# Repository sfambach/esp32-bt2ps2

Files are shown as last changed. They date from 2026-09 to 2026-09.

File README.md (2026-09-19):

1/9/24: Serial Mouse support is out for v0.7! Check notes on [release](https://github.com/Hamberthm/esp32-bt2ps2/releases)

24/8/24: Mouse and Multimedia Key support is out for v0.6! Check notes on release

Tested Bluetooth Keyboards and Mice (Please add your own!): [Excel spreadsheet](https://1drv.ms/x/c/496a36eb8f7bab52/EVKre4_rNmoggEllRQIAAAABdvU2lrtNIQN1tRJOs5V3sw?e=jx4JUH)

FreeRTOS ticking rate of 1000hz and other configs are critical. Be sure to use the default SDKconfig.defaults file included!

# ESP32 Bluetooth/BLE to PS/2 keyboard/mouse adapter

## Hardware (this fork)

This fork adds **carrier boards** for the adapter in [`hardware/`](hardware/README.md): an SMD and a THT version,
each for a plugged-in *D1 mini ESP32* or a soldered-on *ESP32-WROOM-32E*, with level shifters and a 4-pin
connector for a PS/2 or AT keyboard cable. KiCad 10 files, Gerbers for JLCPCB and schematics are included;
downloads are on the [release v0.1](https://github.com/sfambach/esp32-bt2ps2/releases/tag/v0.1).

> ⚠️ **The boards are not tested yet** — designed and DRC-checked, but not manufactured. Details and open points in
> [`hardware/README.md`](hardware/README.md).

| SMD | THT |
|---|---|
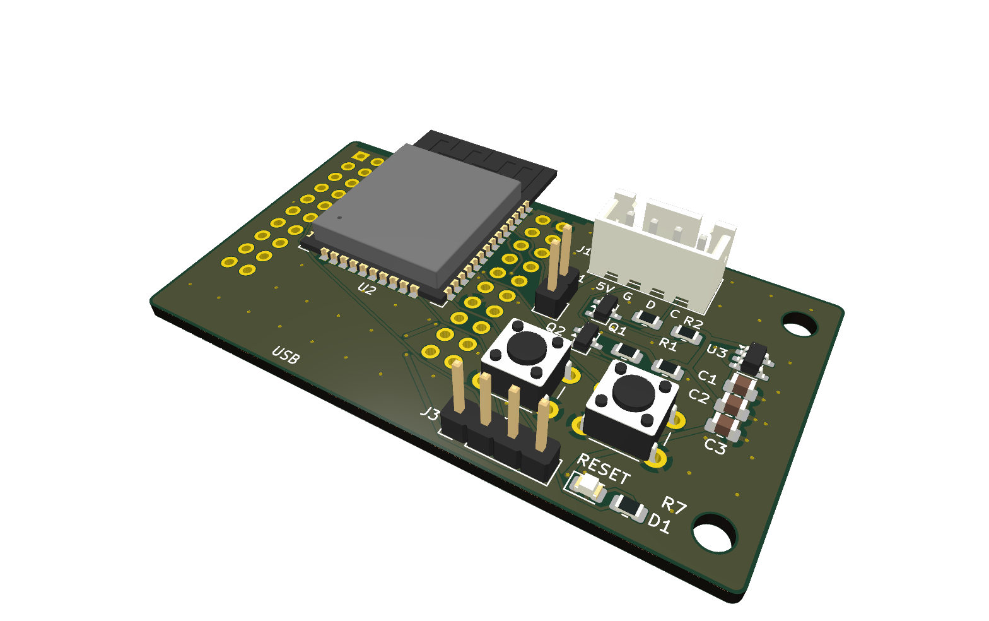
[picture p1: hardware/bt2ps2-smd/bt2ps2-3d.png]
SMD board
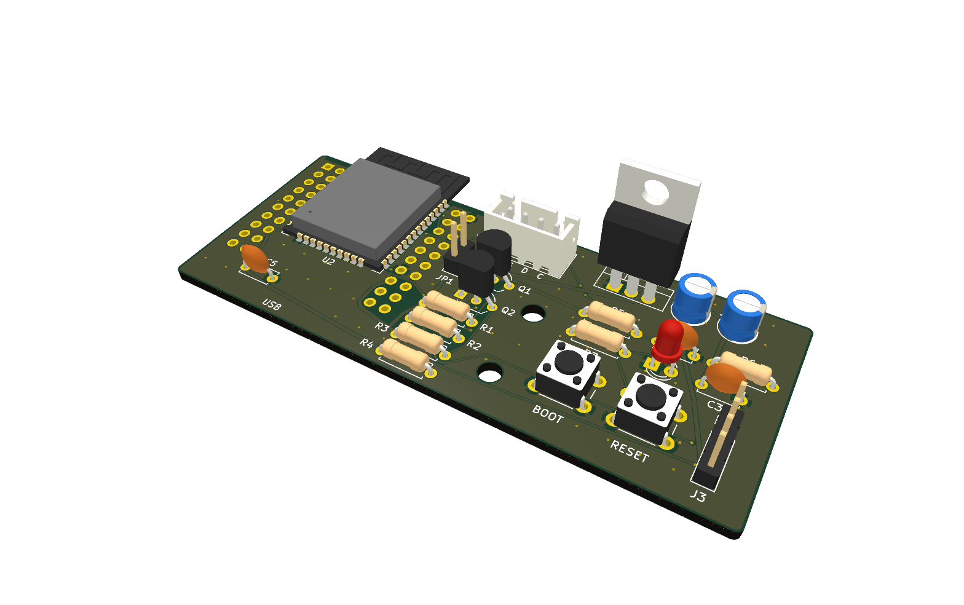
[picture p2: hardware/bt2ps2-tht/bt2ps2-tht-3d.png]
THT board
|  |  |
| SMD schematic | THT schematic |

Project to adapt a Bluetooth or BLE keyboard and/or mouse to use on a computer with compatible PS/2 keyboard/mouse connector/s, wirelessly.
Note that big DIN 5 pin connectors ("AT" keyboard) and Mini-DINs (the violet ones) are equally supported.

YouTube demo: https://youtu.be/2PVjWfAAJFE

<p align="center">
  Mini-DIN version
</p>

# Compatibility

Tested Bluetooth Keyboards and Mice (Please add your own!): https://1drv.ms/x/s!AlKre4_rNmpJiYpl1v4KcbK1Pm77zA?e=0I6QRB

Working under latest ESP-IDF v5.3.0 (not v5.3.3 or higher), compiled on Visual Studio Code. Multi-device support may not work on lower versions of the SDK.

**Developed and tested on the ESP32 DevKit rev 1 board, other variants may not work!**

WARNING: This project is for use in a plain ESP-32 module with BLE and BT Classic support and dual core processor. If you have another variant like C3, you'll have to adapt the code.

* ESP32 S3/C3 (BLE only boards): Check https://github.com/Hamberthm/esp32-bt2ps2/issues/3
* USB-HID instead of PS/2: Check https://github.com/Hamberthm/esp32-bt2ps2/issues/4

# Electrical connections

DIN and Mini-DIN connectors have similar pinout but in different arrangements.

Please use a multimeter and online info to make your cable. Beware of voltage present on the port, you can short and fry things!

Connections:

| ESP32 pin | PS/2 pin | example color | Notes |
| --- | --- | --- |  --- |
| 23 or any | DATA | orange | Repeat on other pin for mouse bus  |
| 22 or any | CLK | white | Repeat on other pin for mouse bus  |
| GND | GND | black | Always connect! |
| Vin | +5v | red | Disconnect if using USB power! |

You can change the DATA and CLK pins to whatever suits your fancy using these lines in the main.cpp file:

```cpp
const int KB_CLK_PIN = 22;
const int KB_DATA_PIN = 23;

const int MOUSE_CLK_PIN = 26;
const int MOUSE_DATA_PIN = 25;
```
Note: Pin 12 & 13 are ideal to solder a connector so you can use Vin, GND, 13 and 12 all in a row (ESP32 DevKit rev 1 boards). BEWARE that pin 12 is a strapping pin on the ESP32 and the module will FAIL to boot due to high signals from the PS/2 port. You can remove the strapping function of pin 12 by blowing an [eFuse](https://docs.espressif.com/projects/esptool/en/latest/esp32s2/espefuse/index.html) on your board. Use the following command:

```
python espefuse.py --port COM4 set_flash_voltage 3.3V
```

Also, applying voltage to pins 1 & 3 (U0 TXD and RXD) could cause the serial communication not to work, thus making serial console output impossible. Be careful on the ones you choose!

There is no need to connect the 5 volts from the port if you wish to power the board over USB. For debugging I recommend you leave it disconnected, as you can end up back-feeding 5 volts back to the PS/2 port, bad things can happen. Once all is working and you don't want to debug anymore, the 5 volts from the port are enough to power the board over the Vin (regulated) pin, making this a pretty neat standalone device!

NOTE: Don't leave the GND cable from the PS2 port floating, otherwise communication won't work! Always connect GND cable to the board even if you're using external power.

Note: ESP32 is **unofficially** 5V tolerant, so you can directly connect PS/2 pins to the board, that's my setup on my rev v1 board and I had no problems. However, you may use a logic level converter.

# Building and flashing

*Note there's a binary release available!

Project works as-is under Visual Studio Code (2024). You need to have the Espressif IDF extension installed and the v5.3.0 of the ESP-IDF SDK. Workflow is as follows:

1- Install Visual Studio Code

2- On the left, open the extensions panel

3- Search and install the Espressif IDF extension

4- Open the command prompt pressing Ctrl+Shift+P

5- Execute command "ESP-IDF: Configure ESP-IDF extension"

6- Select Express, and under "Select ESP-IDF version" choose v5.3.0 (As of 19/6/25 v5.3.3 or higher are NOT working!)

7- After installation, select File > Open Folder and open the ESP32-BT2PS2 project folder

8- Start building by pressing Ctrl+E and then B, or using the Build button in the bottom bar

9- If succesfully built, connect and flash your ESP32 board (Ctrl+E then F, or the flash button)

Refer to the following link for more instructions:

* https://github.com/espressif/vscode-esp-idf-extension/blob/master/docs/tutorial/install.md

Once succesfully built and flashed, you're ready to rock! (your BLE keyboard on an ancient computer, that is).

# Usage and debugging

Once powered up and first of all, the code will create and init an `esp32_ps2dev::PS2Keyboard` object, so it can start to talk to the computer as soon as possible. This is critical because during boot the BIOS can send different commands to the module to test the presence of the keyboard.

After PS/2 init, the module scans for nearby Bluetooth and BLE devices. If the last bonded keyboard is in range, it will try to connect to it using the keys stored on the NVS flash, so no pairing is needed for every connection. If it doesn't detect a previously bonded device, it will try to connect to the nearest keyboard in pairing mode. If both processes fail, it will wait one second and scan again until it finds anything.

IMPORTANT: Is recommended to do the pairing to the keyboard BEFORE connecing the board to a PS/2 port. For this, connect a charger or power bank to the ESP's USB port and pair your device more comfortably.

For v0.6, you can invoke pairing during execution (blue LED on) at any time. Press the "BOOT" button on the rev v1 board, essentially shorting GPIO_0 to ground. LED will go off and enter pairing mode. To cancel pairing, press and hold for 3 seconds (pairing aborting does not work on startup pairing).

**LED off: Pairing mode activated. LED on: normal execution, only previously paired devices can connect at any time.**

### >> BLE KEYBOARD OR MOUSE PAIRING: 
Set keyboard or mouse in pairing mode and power on the board. No code entry required.

### >> BLUETOOTH CLASSIC KEYBOARD PAIRING (code pairing):

1- Set keyboard in pairing mode and power on the board.

2- Wait until you see a short blast of quick flashes, then pay attention:

3- For each code digit, the board will flash the LED the number of times equal to the digit.

4- Press each digit on the keyboard as you read them (do not wait until it finishes! Some keyboards have a timeout).

5- If the digit is 0, a steady light will show for 1.5 seconds instead of the digit.

6- When you see the blast of quick flashes again, press ENTER.

OR you can always look at the code using the Serial monitor console, whatever you find easier, you fancy boy.

### >> BLUETOOTH CLASSIC KEYBOARD PAIRING, LEGACY PROCEDURE (legacy code pairing):

In older keyboards, the user must enter a custom code on the host device and then on the keyboard. Since we can't input it easily on the ESP32, the code is fixed to 1234.

1- Set keyboard in pairing mode and power on the board

2- Watch the Serial Ouput Console. Wait for the board finishing the scan and for the message "Waiting pairing code entry..."

3- Type 1234 on the keyboard then press ENTER.

Note: For Legacy Mode, no LED output is possible at the moment, so we need to check the serial console for the right time to enter the code. 

---

- If paired and working correctly, the board should blink the LED with each key press on the keyboard, or with each click on the mouse

Once connected you can start using your keyboard and mouse, blue LED should be on. Remove any USB power source and connect the board to the PS/2 compatible system and enjoy. Remember PS/2 is NOT a HOT-SWAP protocol, please only connect the board with the system totally OFF.

You can hot-disconnect the keyboard and mouse for models that support multiple devices hopping. The module will detect the disconnection and repeatedly try to reconnect while you're using other systems, so it will be back online as soon as the keyboard gets up to the ESP32 again. This is critical for keyboards/mouses that go to sleep and disconnect, or if you swap between computers using a multi-connection keyboard. 

Please note that pairing is only done after power up. If you wish to pair a new device, please reset the module with the reset button or power off and on the computer (not just reset it, because we need a power cycle). Note that if a previously paired device is on and in range, it will always connect to it first. Also invoke pairing after power on (LED on) by using the BOOT button or shorting GPIO_0 to ground.

In case something doesn't work, you'll need to debug. 

If the blue light on the module lights up and your keyboard connects, but it doesn't work, first of all reset your system. If it still doesn't work, then you'll need to enable debugging in the `esp32-ps2dev.cpp` file using `#DEFINE _ESP32_PS2DEV_DEBUG_`. Check for "PS/2 command received" messages and see where it hangs, or what the BIOS doesn't like. This is advanced so if you need help, make a new issue.

# TODO
 * Test on many keyboards and mouses.
 * Improve stability.
 * Clean up the code.
 * Test against various hosts.

# Reference
- http://www-ug.eecg.toronto.edu/msl/nios_devices/datasheets/PS2%20Protocol.htm
- http://www-ug.eecg.toronto.edu/msl/nios_devices/datasheets/PS2%20Mouse%20Protocol.htm
- http://www-ug.eecg.toronto.edu/msl/nios_devices/datasheets/PS2%20Keyboard%20Protocol.htm

# History
Using code and hard work from these folks:
 
 * https://playground.arduino.cc/ComponentLib/Ps2mouse/
 * https://github.com/grappendorf/arduino-framework/tree/master/ps2dev
 * https://github.com/dpavlin/Arduino-projects/tree/master/libraries/ps2dev
 * ps2 library Written by Chris J. Kiick, January 2008. https://github.com/ckiick
 * modified by Gene E. Scogin, August 2008.
 * modified by Tomas 'Harvie' Mudrunka 2019. https://github.com/harvie/ps2dev
 * modified for ESP32 by hrko 2022. https://github.com/hrko/esp32-ps2dev
 * fixed for PC compatibility and stability by Hambert, 2023. https://github.com/Hamberthm/esp32-ps2dev
 * bt-keyboard library by Guy Turcotte, 2022. https://github.com/turgu1/bt-keyboard
 * adapted to Arduino IDE and added improvements by Hambert, 2023. https://github.com/Hamberthm/bt-keyboard

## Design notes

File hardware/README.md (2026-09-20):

# Hardware: carrier boards for esp32-bt2ps2

> ⚠️ **Untested.** These boards have been designed and checked (KiCad ERC/DRC clean), but **no board has been
> manufactured or tested yet**. Use at your own risk and check everything with a multimeter before connecting
> it to a computer. Feedback welcome.
>
> ⚠️ **Noch nicht getestet.** Die Platinen sind entworfen und geprüft (ERC/DRC ohne Befund), aber **noch nicht
> gefertigt und nicht erprobt.**

Two boards for the firmware in this repository — **keyboard only (version 1)**, same pins as the firmware
defaults (`KB_CLK_PIN = 22`, `KB_DATA_PIN = 23`), so the firmware runs unchanged.

| | [SMD](bt2ps2-smd) | [THT](bt2ps2-tht) |
|---|---|---|
| ESP32 | **A:** D1 mini ESP32 plugged in, **or B:** ESP32-WROOM-32E soldered on | same |
| Level shifter 5 V ↔ 3.3 V | 2 × BSS138 (SOT-23) + 10 kΩ | 2 × 2N7000 (TO-92) + 10 kΩ |
| 3.3 V regulator (variant B only) | AP2112K-3.3 | LD1117V33 (TO-220) |
| Passives | 0805 | through-hole (the WROOM is the only SMD part) |
| Size | 61.0 × 34.1 mm | 83.0 × 34.1 mm |

Both are 2-layer boards made for JLCPCB's standard process (1.6 mm, 1 oz, HASL). Designed with **KiCad 10**.

**Downloads:** Gerber ZIPs, KiCad projects and schematics are attached to the
[release v0.1](https://github.com/sfambach/esp32-bt2ps2/releases/tag/v0.1).

## SMD board

SMD board, 3D view

SMD schematic

## THT board

THT board, 3D view

THT schematic

## Enclosures

3D-printable cases for both boards (shell + lid, OpenSCAD source and STLs) are in [`case/`](case/README.md).

## What is on the board

- **J1 – keyboard connector to the PC** (JST-XH, 4 pins): `1 = +5V`, `2 = GND`, `3 = DATA`, `4 = CLK` (printed as
  `5V G D C`). Crimp a cable to a PS/2 (Mini-DIN-6) or AT (DIN-5) plug:

  | J1 | PS/2 Mini-DIN-6 pin | AT DIN-5 pin |
  |---|---|---|
  | 1 +5V | 4 | 5 |
  | 2 GND | 3 | 4 |
  | 3 DATA | 1 | 2 |
  | 4 CLK | 5 | 1 |

  Pinouts as commonly documented — **measure your plug before use.**
- **JP1 – 5 V from the PC.** Pull the jumper while the board is powered over USB (or J3), otherwise 5 V is fed back
  into the PC's keyboard port — the same warning as in the main README.
- **Variant A (default):** a *D1 mini ESP32* (MH-ET LIVE MiniKit / "D1 mini ESP32 ESP-WROOM-32", 4 rows of pins,
  39 × 32 mm) on female headers. Programming via its own USB port. Its USB end is flush with the board edge,
  its antenna overhangs the opposite edge.
- **Variant B:** an ESP32-WROOM-32E soldered between the inner header rows, antenna over the board edge. Adds the
  3.3 V regulator, EN/BOOT circuitry, **BOOT** and **RESET** buttons, a status LED on IO2 and **J3** for a
  USB-serial adapter: `1 GND`, `2 ESP TXD → adapter RX`, `3 ESP RXD → adapter TX`, `4 +5V`.
  Populate **either A or B**, never both.
- IO25/IO26 are kept free for the mouse port (planned for version 2).

## Files per board

| File | |
|---|---|
| `*.kicad_pro`, `*.kicad_sch`, `*.kicad_pcb` | KiCad 10 project |
| `*.kicad_dru` | design rules for JLCPCB |
| `*.kicad_sym`, `*.pretty/` | symbol and footprint of the D1 mini ESP32 socket |
| `*-schaltplan.pdf` / `.svg` | schematic |
| `fertigung/*-jlcpcb-gerber.zip` | Gerber + drill files, ready to upload to JLCPCB |
| `fertigung/bestueckung-*.pdf` | assembly drawings |
| `fertigung/*-ibom.html` | interactive BOM (open in a browser) |
| `fertigung/stueckliste.csv` | bill of materials |
| `fertigung/*-jlcpcb-positionen.csv` | pick-and-place data, origin at the lower left corner of the board |

## Notes and open points

- **2N7000 at 3.3 V gate (THT board):** Vgs(th) is typically 2.1 V but may be up to 3 V. It should work for the
  low PS/2 currents — try it on a breadboard first. A BS170 is *not* a drop-in replacement (different pinout).
- The D1 mini footprint is based on [r0oland/ESP32_mini_KiCad_Library](https://github.com/r0oland/ESP32_mini_KiCad_Library)
  and was checked against the pinout of an actual board; the outline and antenna position are estimated (±1 mm).
- The traces were laid out by a simple grid router and checked with KiCad's DRC — functional, not pretty.

Designed by Stefan Fambach — [fambach.net](https://www.fambach.net). The hardware in this folder is licensed under the
[MIT License](LICENSE), like the firmware.

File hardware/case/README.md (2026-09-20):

# 3D-printed enclosures

One OpenSCAD file, two enclosures (SMD and THT board). Each is **split horizontally at half height**: a bottom tray and a top frame with the cover plate.

| | SMD board | THT board |
|---|---|---|
| Assembled, outer | 72.3 × 49.8 × 24.6 mm | 94.3 × 49.8 × 24.6 mm |
| Bottom / top | 12.0 mm / 12.6 mm tall | same |
| STL | `bt2ps2-smd-unterteil.stl` (bottom), `bt2ps2-smd-oberteil.stl` (top) | `bt2ps2-tht-unterteil.stl`, `bt2ps2-tht-oberteil.stl` |

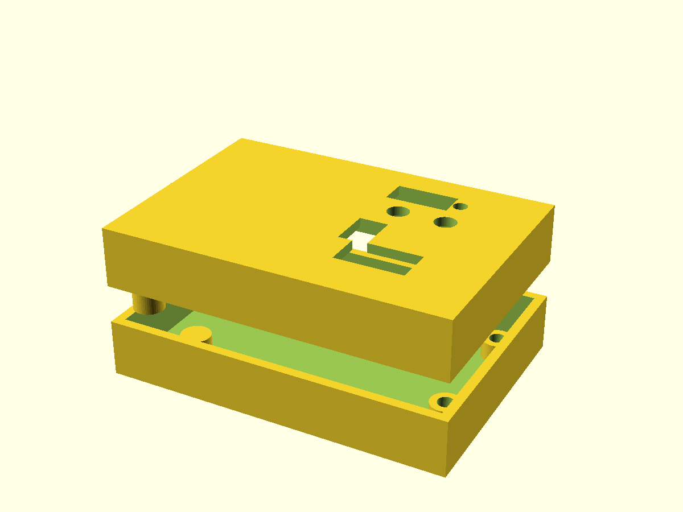
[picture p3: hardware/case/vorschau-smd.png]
SMD enclosure


The box is larger than the board because the ESP32 module sticks out at both ends: the antenna (7 mm of air, no
copper and no screw underneath) and the D1 mini's USB socket (4.6 mm).

**How it holds together:** four M3 screws, all from below. They pass through the bottom tray into columns that hang
down from the top cover. **Two of them go through the board's mounting holes** — the board sits on a 4 mm post of
the bottom part and the column of the top part presses on it, so board and case share the same screw. The other two
stand in the free strip left of the board. Screw heads sit in countersinks, so the case stands flat.

**Openings in the top part:** two buttons (⌀4.6 mm), LED (⌀3.0 mm SMD board, ⌀3.6 mm THT board), the JST connector J1 (the
cable leaves through it), the 5 V jumper JP1, and the programming header J3. **USB** is a cutout in the side wall
at socket height.

**You need:** tactile switches **6 × 6 mm with a long plunger, 17 mm overall** ("6x6x17") — then the plunger ends
flush with the cover; and four M3 × 16 self-tapping screws (2.5 mm pilot holes); M3 × 12 works too.

**Rebuild or modify** — wall thickness, inner height, clearances and every cutout are parameters at the top of
[`bt2ps2-gehaeuse.scad`](bt2ps2-gehaeuse.scad):

```bash
openscad -D 'variante="smd"' -D 'teil="unterteil"' -o bt2ps2-smd-unterteil.stl bt2ps2-gehaeuse.scad
```

`variante` is `smd` or `tht`, `teil` is `unterteil` (bottom), `oberteil` (top) or `beides` (both, for viewing only).
Print the top part upside down — the columns then point upwards and need no supports.

> ⚠️ **Untested like the boards:** dimensions are taken from the KiCad files, but nothing has been printed or
> fitted yet. Print a test corner with one screw post and one button hole first.

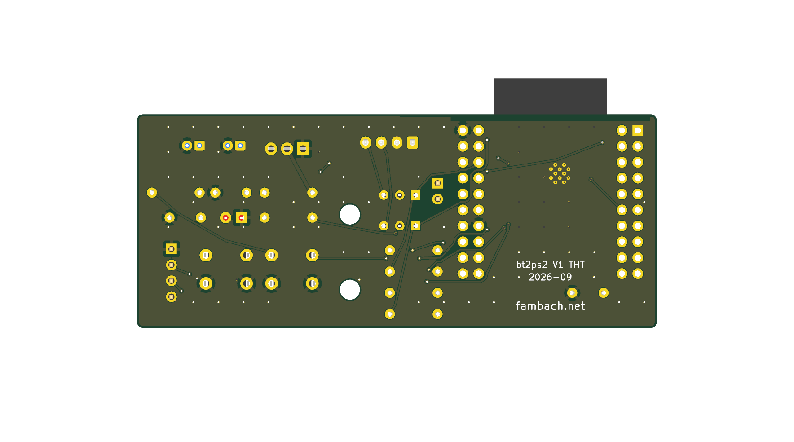
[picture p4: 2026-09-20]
hardware/bt2ps2-tht/bt2ps2-tht-unten.png

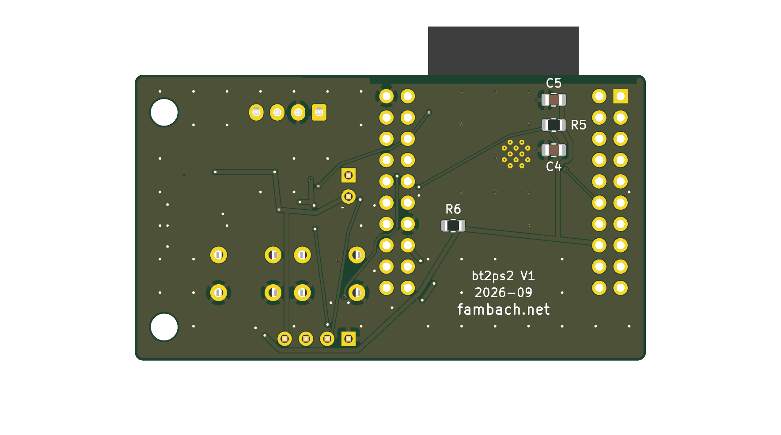
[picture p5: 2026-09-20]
hardware/bt2ps2-smd/bt2ps2-unten.png

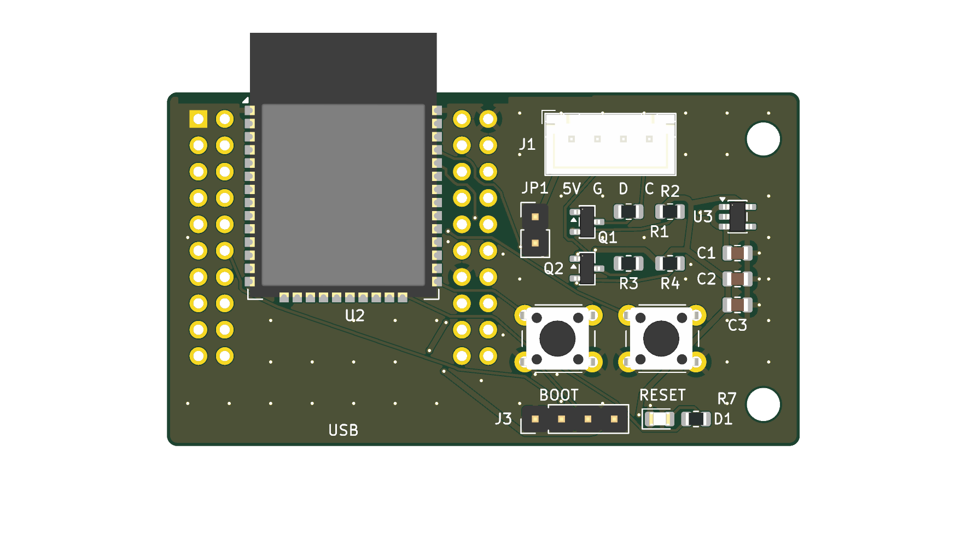
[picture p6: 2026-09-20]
hardware/bt2ps2-smd/bt2ps2-oben.png

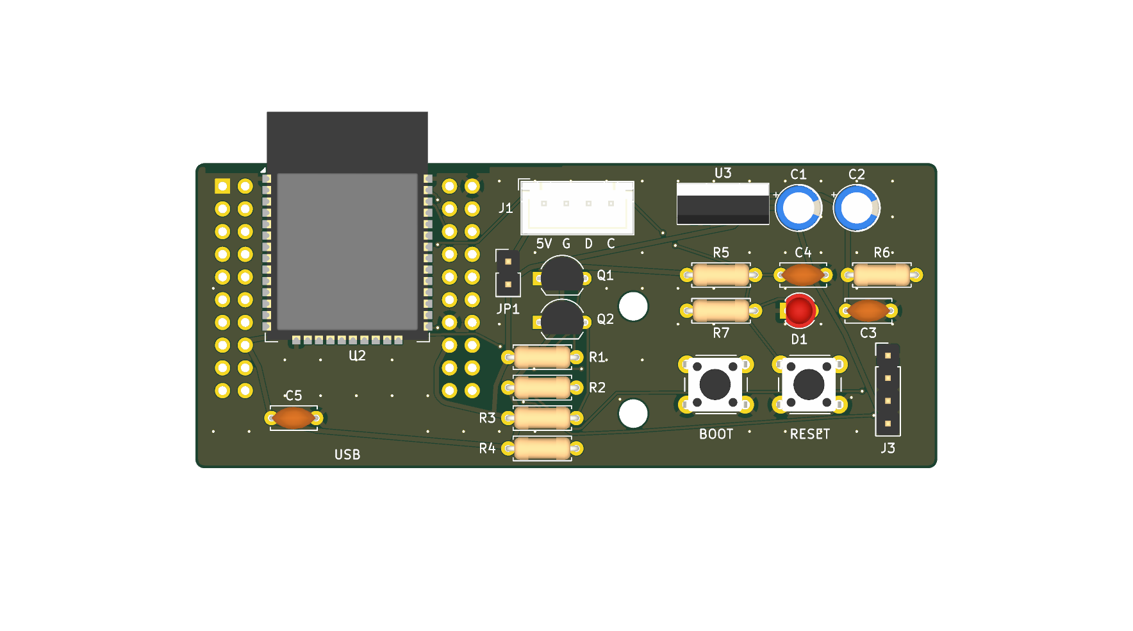
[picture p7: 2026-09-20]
hardware/bt2ps2-tht/bt2ps2-tht-oben.png

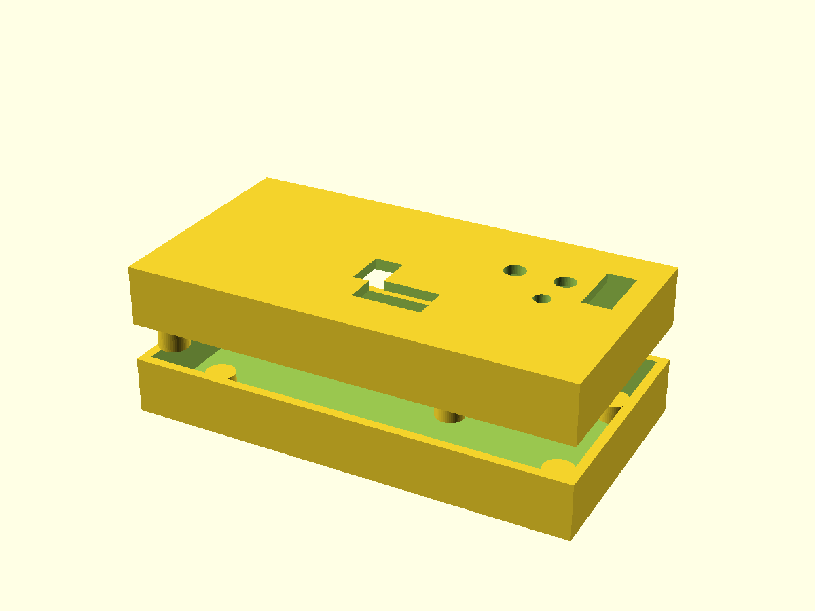
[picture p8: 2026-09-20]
hardware/case/vorschau-tht.png

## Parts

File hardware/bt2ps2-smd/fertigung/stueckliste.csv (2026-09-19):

Bauteile | Wert | Gehaeuse | Anzahl
C1,C2 | 10u | Capacitor_SMD:C_0805_2012Metric | 2
C3,C5 | 100n | Capacitor_SMD:C_0805_2012Metric | 2
C4 | 1u | Capacitor_SMD:C_0805_2012Metric | 1
D1 | blau | LED_SMD:LED_0805_2012Metric | 1
J1 | PS2_Tastatur | Connector_JST:JST_XH_B4B-XH-A_1x04_P2.50mm_Vertical | 1
J3 | Programmer | Connector_PinHeader_2.54mm:PinHeader_1x04_P2.54mm_Vertical | 1
JP1 | 5V_vom_PC | Connector_PinHeader_2.54mm:PinHeader_1x02_P2.54mm_Vertical | 1
Q1,Q2 | BSS138 | Package_TO_SOT_SMD:SOT-23 | 2
R1-R6 | 10k | Resistor_SMD:R_0805_2012Metric | 6
R7 | 1k | Resistor_SMD:R_0805_2012Metric | 1
SW1 | BOOT | Button_Switch_THT:SW_PUSH_6mm | 1
SW2 | RESET | Button_Switch_THT:SW_PUSH_6mm | 1
U1 | D1_mini_ESP32 | bt2ps2:D1_mini_ESP32_Sockel | 1
U2 | ESP32-WROOM-32E-N4 | RF_Module:ESP32-WROOM-32E | 1
U3 | AP2112K-3.3 | Package_TO_SOT_SMD:SOT-23-5 | 1

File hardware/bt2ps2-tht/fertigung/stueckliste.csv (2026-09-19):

Bauteile | Wert | Gehaeuse | Anzahl
C1,C2 | 10u | Capacitor_THT:CP_Radial_D5.0mm_P2.00mm | 2
C3,C5 | 100n | Capacitor_THT:C_Disc_D5.0mm_W2.5mm_P5.00mm | 2
C4 | 1u | Capacitor_THT:C_Disc_D5.0mm_W2.5mm_P5.00mm | 1
D1 | blau | LED_THT:LED_D3.0mm | 1
J1 | PS2_Tastatur | Connector_JST:JST_XH_B4B-XH-A_1x04_P2.50mm_Vertical | 1
J3 | Programmer | Connector_PinHeader_2.54mm:PinHeader_1x04_P2.54mm_Vertical | 1
JP1 | 5V_vom_PC | Connector_PinHeader_2.54mm:PinHeader_1x02_P2.54mm_Vertical | 1
Q1,Q2 | 2N7000 | Package_TO_SOT_THT:TO-92_Inline_Wide | 2
R1-R6 | 10k | Resistor_THT:R_Axial_DIN0207_L6.3mm_D2.5mm_P7.62mm_Horizontal | 6
R7 | 1k | Resistor_THT:R_Axial_DIN0207_L6.3mm_D2.5mm_P7.62mm_Horizontal | 1
SW1 | BOOT | Button_Switch_THT:SW_PUSH_6mm | 1
SW2 | RESET | Button_Switch_THT:SW_PUSH_6mm | 1
U1 | D1_mini_ESP32 | bt2ps2-tht:D1_mini_ESP32_Sockel | 1
U2 | ESP32-WROOM-32E-N4 | RF_Module:ESP32-WROOM-32E | 1
U3 | LD1117V33 | Package_TO_SOT_THT:TO-220-3_Vertical | 1

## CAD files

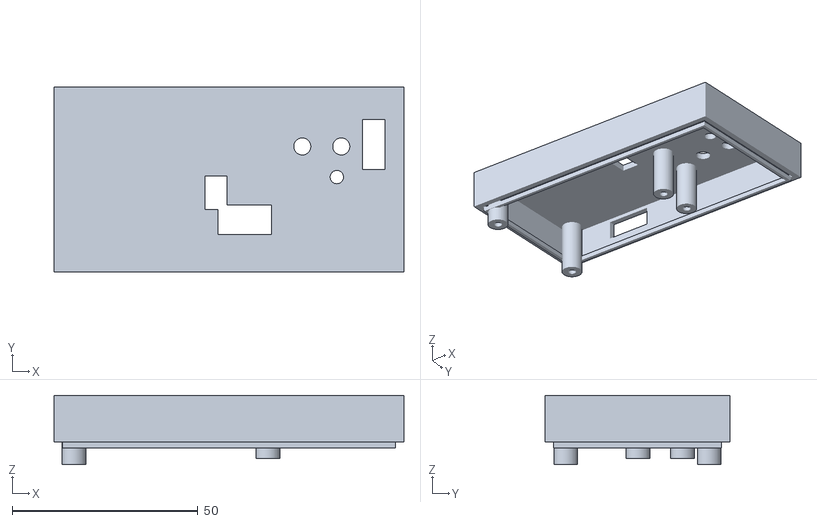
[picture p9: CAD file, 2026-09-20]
hardware/case/bt2ps2-tht-oberteil.stl
94.3 x 49.8 x 18.6

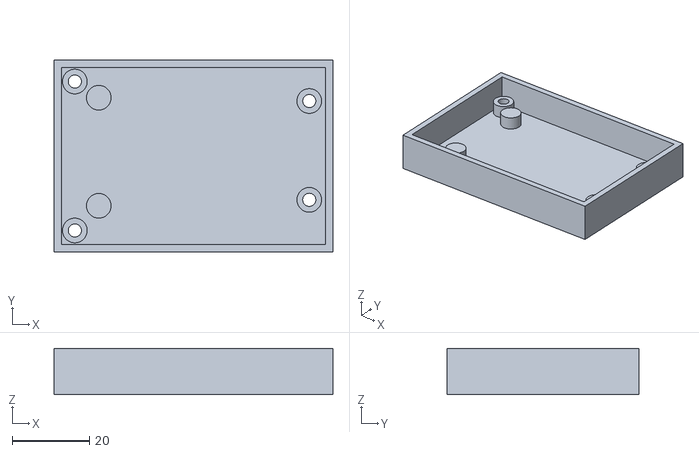
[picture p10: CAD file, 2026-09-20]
hardware/case/bt2ps2-smd-unterteil.stl
72.3 x 49.8 x 12.0

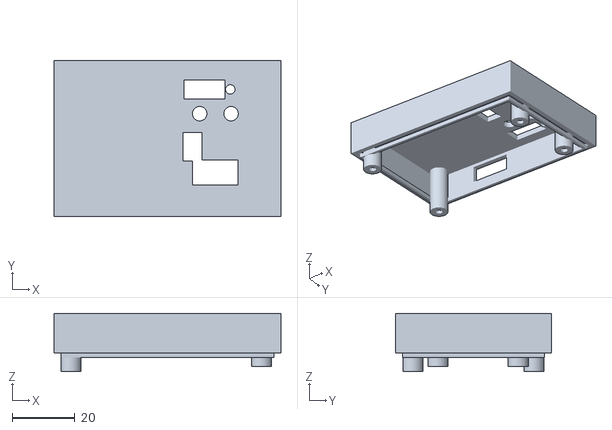
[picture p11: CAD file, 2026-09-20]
hardware/case/bt2ps2-smd-oberteil.stl
72.3 x 49.8 x 18.6

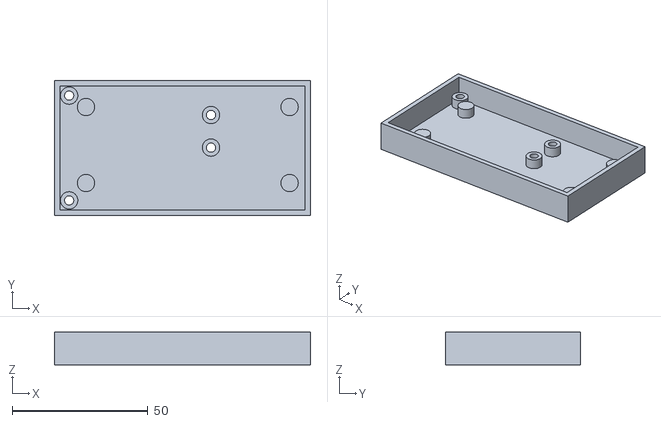
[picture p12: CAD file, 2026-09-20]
hardware/case/bt2ps2-tht-unterteil.stl
94.3 x 49.8 x 12.0

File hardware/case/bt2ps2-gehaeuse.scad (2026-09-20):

// Gehäuse für die zwei BT2PS2-Platinen (SMD und THT), zum 3D-Drucken.
// Maße aus den KiCad-Platinen gemessen (Platinenkoordinaten, Ursprung oben links, y nach unten;
// y = 0 ist die Antennenseite, y = Platinenhöhe die USB-Seite).
//
// Aufbau: waagerecht geteilt. Das Unterteil ist eine flache Wanne, das Oberteil ein Rahmen mit Deckplatte.
// Vier Schrauben M3 kommen von unten durch das Unterteil und ziehen in die Säulen des Oberteils.
// Zwei davon gehen durch die Montagelöcher der Platine — die Platine hängt also an der Gehäuseverschraubung.
//
// Aufruf:
//   openscad -D 'variante="smd"' -D 'teil="unterteil"' -o unterteil.stl bt2ps2-gehaeuse.scad
//   openscad -D 'variante="tht"' -D 'teil="oberteil"'  -o oberteil.stl  bt2ps2-gehaeuse.scad
//
// Taster: 6 × 6 mm mit langem Schaft, Gesamthöhe ab Platine 17 mm ("6x6x17"). Der Schaft schliesst dann oben
// mit der Deckplatte ab. Kürzere Schäfte (13 mm) erreichen sie nicht.

variante = "smd";        // "smd" oder "tht"
teil     = "unterteil";  // "unterteil", "oberteil" oder "beides"

$fn = 48;

// ── Platinen ───────────────────────────────────────────────────────────────────────────────────
smd = [61.1, 34.2];      // Breite, Höhe der Platine
tht = [83.1, 34.2];
platine = variante == "tht" ? tht : smd;
pb = platine[0];
ph = platine[1];

wand     = 2.0;    // Wandstärke
boden    = 2.0;    // Bodenstärke des Unterteils
deckel_d = 2.0;    // Deckplatte des Oberteils
luft     = 0.6;    // Luft um die Platine
stuetze  = 4.0;    // Platine über dem Boden (Platz für Lötstellen und Teile unten)
dicke    = 1.6;    // Platinendicke
innen_h  = 15.0;   // Luft über der Platine (höchstes Teil: USB-Buchse des D1 mini, 12,1 mm)

oben_frei  = 7.0;  // Überstand der Antenne über die Platinenkante
unten_frei = 4.6;  // Überstand des D1 mini mit der USB-Buchse
links_frei = 6.0;  // Streifen neben der Platine für die zwei linken Schraubsäulen

// Höhen über dem Boden (Aussenkante Unterteil = 0)
pl_u   = boden + stuetze;                 // Unterkante Platine   = 6,0
pl_o   = pl_u + dicke;                    // Oberkante Platine    = 7,6
h_ges  = pl_o + innen_h + deckel_d;       // Gesamthöhe           = 24,6
naht   = 12.0;                            // Trennebene, ungefähr auf halber Höhe

// Innenraum in Platinenkoordinaten
ix0 = -luft - links_frei;   ix1 = pb + luft;
iy0 = -oben_frei;           iy1 = ph + unten_frei;
iw  = ix1 - ix0;            ih  = iy1 - iy0;

// ── Merkmale (Mitte der Courtyard-Felder aus KiCad) ────────────────────────────────────────────
usb     = [17.05, ph];
taster  = variante == "tht" ? [[58.30, 24.80], [68.80, 24.80]] : [[37.80, 23.80], [47.80, 23.80]];
led     = variante == "tht" ? [67.60, 16.55] : [47.55, 31.55];
led_d   = variante == "tht" ? 3.6 : 3.0;
j1      = [42.80, 5.08, 14.5, 8.0];       // JST-Stecker: Kabel geht nach oben heraus
jp1     = variante == "tht" ? [35.05, 12.30, 6.0, 9.0] : [35.55, 13.30, 6.0, 9.0];
j3      = variante == "tht" ? [77.55, 25.35, 6.0, 13.5] : [39.35, 31.55, 13.0, 6.0];

// Die zwei Montagelöcher der Platine — hier hält dieselbe Schraube Platine und Gehäuse zusammen
platinen_loecher = variante == "tht" ? [[49.05, 16.05], [49.05, 28.05]] : [[57.55, 4.55], [57.55, 30.15]];
// Die zwei übrigen Schrauben stehen im linken Streifen, wo das Modul nicht hinreicht
rand_loecher = [[ix0 + 3.4, iy0 + 3.6], [ix0 + 3.4, iy1 - 3.6]];
schrauben = concat(platinen_loecher, rand_loecher);
// Auflager ohne Schraube, damit die Platine nicht kippt
auflager = variante == "tht" ? [[3.0, 3.0], [3.0, 31.0], [78.0, 3.0], [78.0, 31.0]] : [[3.0, 3.0], [3.0, 31.0]];

dom_d  = 6.4;    // Aussendurchmesser der Säulen
durch  = 3.4;    // Durchgangsloch M3
kern   = 2.5;    // Kernloch M3 (Blechschraube)
kopf_d = 6.4;    // Senkung für den Schraubenkopf im Boden
kopf_h = 2.0;

// ── Bausteine ──────────────────────────────────────────────────────────────────────────────────
module schale(h) {                 // Aussenkörper von z = 0 bis h
    translate([ix0 - wand, iy0 - wand, 0]) cube([iw + 2 * wand, ih + 2 * wand, h]);
}

module hohlraum(z0, z1) {
    translate([ix0, iy0, z0]) cube([iw, ih, z1 - z0]);
}

module usb_loch() {                // Ausschnitt in der Seitenwand, in Gehäusehöhen
    z = pl_o + 8.5 + 1.0;          // Buchsenleiste + Modulplatine = Unterkante der Buchse
    translate([usb[0] - 7.5, iy1 - 1, z - 1.6]) cube([15, wand + 4, 6.0]);
}

// ── Unterteil: Wanne bis zur Naht, Säulen mit Durchgangsloch, Senkung im Boden ─────────────────
module unterteil() {
    difference() {
        union() {
            difference() {
                schale(naht);
                hohlraum(boden, naht + 1);
            }
            // Säulen bis Unterkante Platine; die Platine liegt darauf
            for (s = schrauben) translate([s[0], s[1], boden]) cylinder(d = dom_d, h = stuetze);
            for (a = auflager) translate([a[0], a[1], boden]) cylinder(d = dom_d, h = stuetze);
        }
        for (s = schrauben) {
            translate([s[0], s[1], -1]) cylinder(d = durch, h = pl_u + 2);
            translate([s[0], s[1], -0.1]) cylinder(d = kopf_d, h = kopf_h);   // Senkung für den Kopf
        }
    }
}

// ── Oberteil: Rahmen mit Deckplatte; Säulen greifen bis auf die Platine hinunter ───────────────
module oberteil() {
    hoehe = h_ges - naht;          // eigene Höhe
    dz    = naht;                  // Gehäusehöhe = eigene Höhe + dz
    difference() {
        union() {
            difference() {
                translate([0, 0, 0]) schale(hoehe);
                hohlraum(-1, hoehe - deckel_d);
                translate([0, 0, -dz]) usb_loch();
            }
            // Rand, der in das Unterteil greift
            translate([ix0 + 0.3, iy0 + 0.3, -1.5]) difference() {
                cube([iw - 0.6, ih - 0.6, 1.5]);
                translate([1.2, 1.2, -0.1]) cube([iw - 3.0, ih - 3.0, 1.7]);
            }
            // Säulen von der Deckplatte bis auf die Platine (bzw. bis auf die Säule des Unterteils)
            for (s = platinen_loecher) translate([s[0], s[1], pl_o - dz]) cylinder(d = dom_d, h = hoehe - deckel_d - (pl_o - dz));
            for (s = rand_loecher)     translate([s[0], s[1], pl_u - dz]) cylinder(d = dom_d, h = hoehe - deckel_d - (pl_u - dz));
        }
        // Kernloch durch alle Säulen, von unten offen
        for (s = schrauben) translate([s[0], s[1], pl_u - dz - 1]) cylinder(d = kern, h = hoehe);
        for (t = taster) translate([t[0], t[1], hoehe - deckel_d - 1]) cylinder(d = 4.6, h = 10);
        translate([led[0], led[1], hoehe - deckel_d - 1]) cylinder(d = led_d, h = 10);
        for (o = [j1, jp1, j3])
            translate([o[0] - o[2] / 2, o[1] - o[3] / 2, hoehe - deckel_d - 1]) cube([o[2], o[3], 10]);
    }
}

if (teil == "unterteil" || teil == "beides") unterteil();
if (teil == "oberteil") oberteil();
if (teil == "beides") translate([0, 0, naht + 8]) oberteil();

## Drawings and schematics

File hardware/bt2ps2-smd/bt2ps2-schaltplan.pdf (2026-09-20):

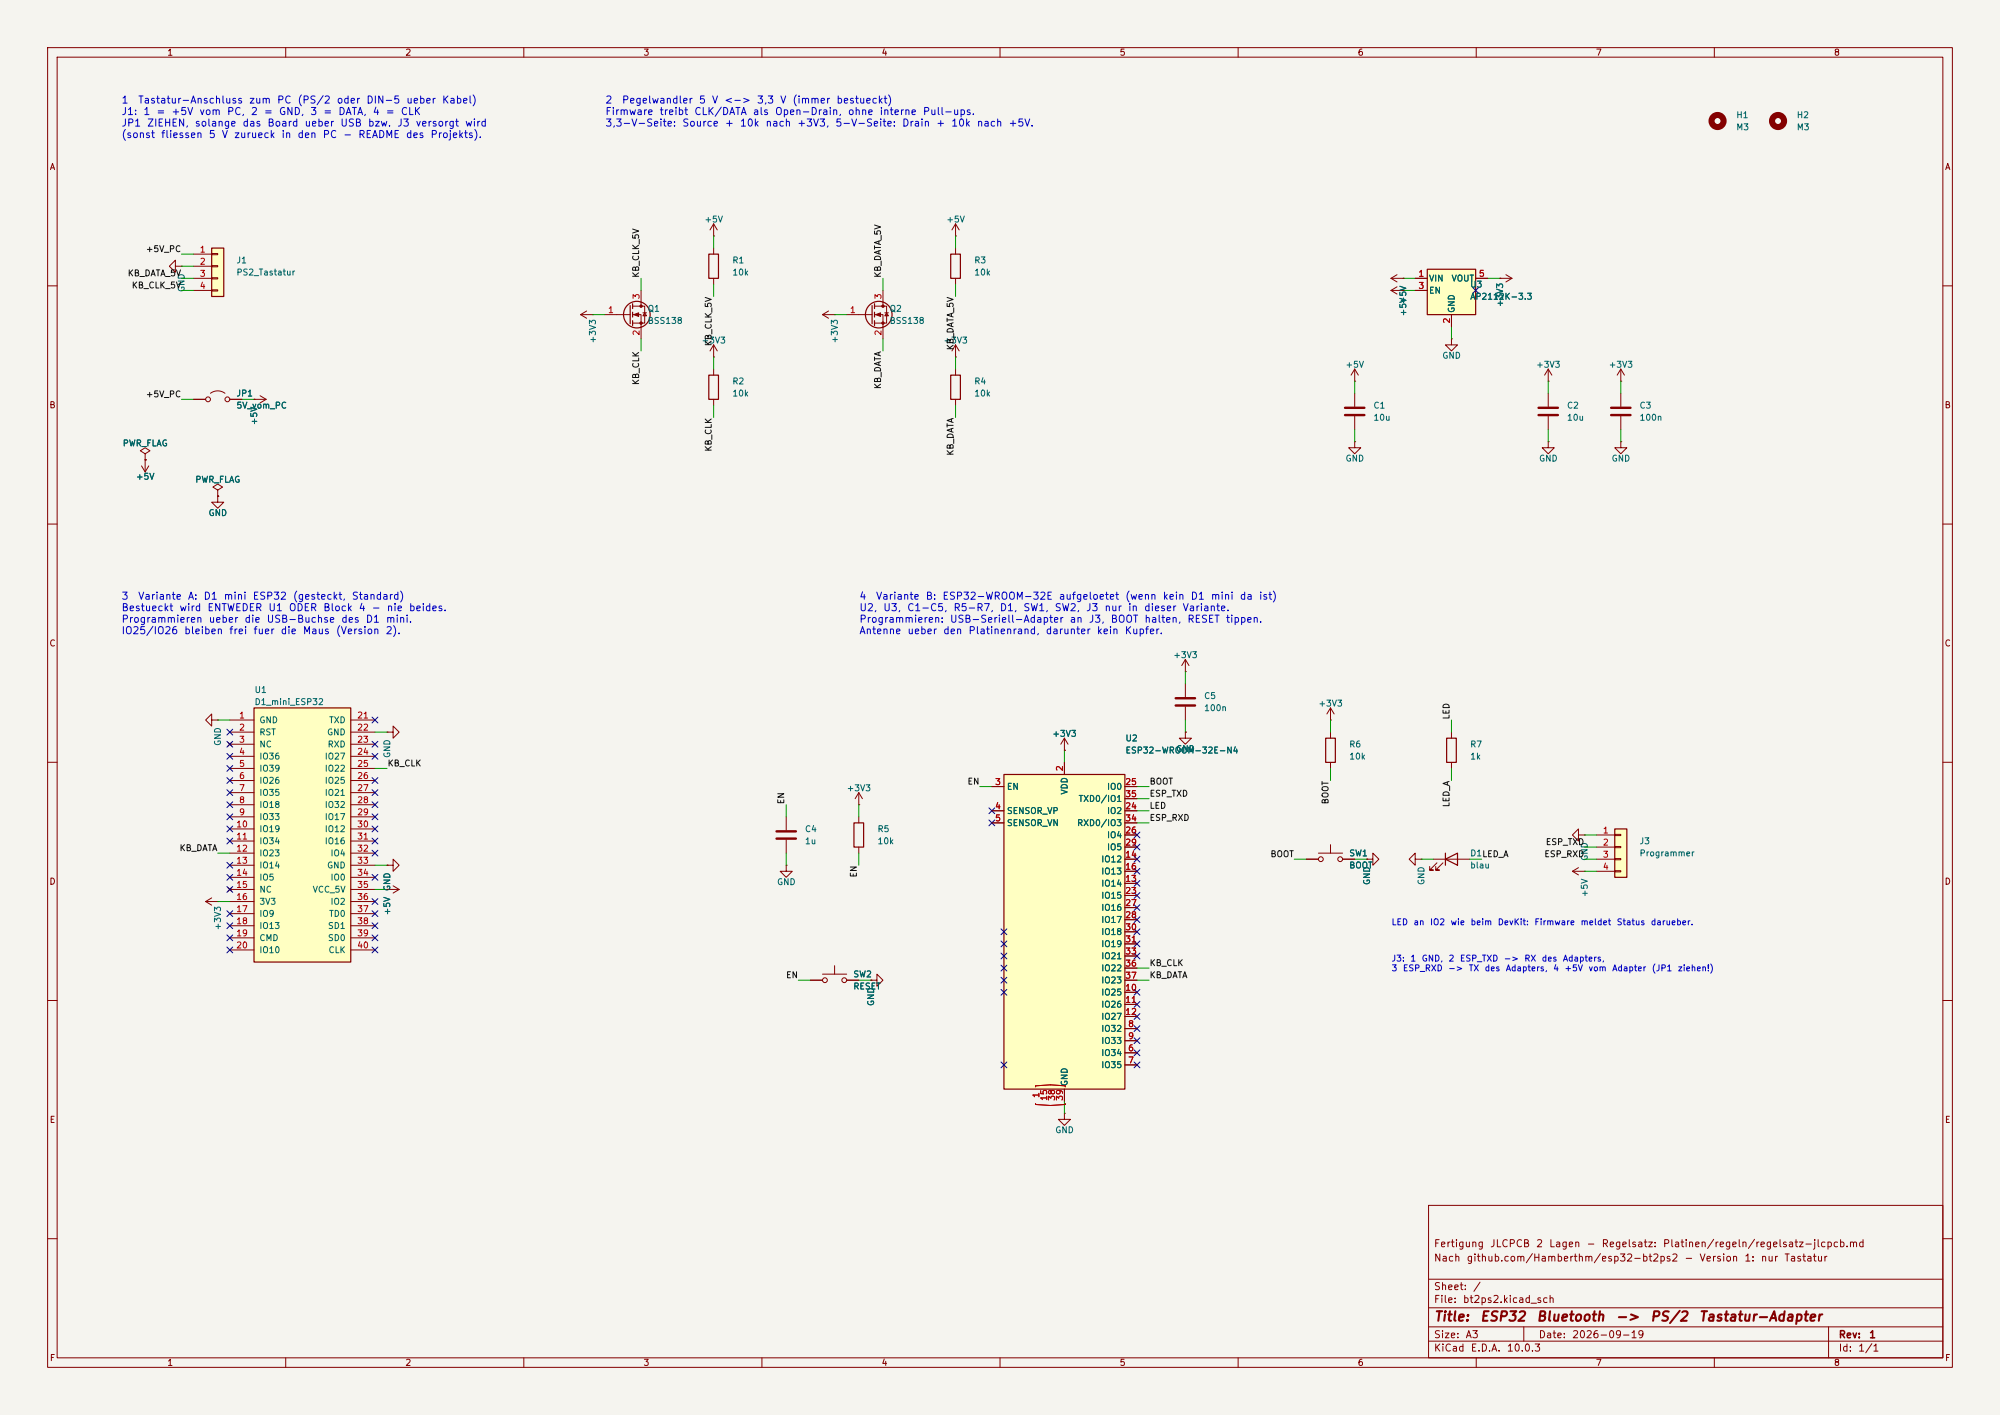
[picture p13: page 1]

1 Tastatur-Anschluss zum PC (PS/2 oder DIN-5 ueber Kabel)
J1: 1 = +5V vom PC, 2 = GND, 3 = DATA, 4 = CLK
JP1 ZIEHEN, solange das Board ueber USB bzw. J3 versorgt wird

2 Pegelwandler 5 V <-> 3,3 V (immer bestueckt)
Firmware treibt CLK/DATA als Open-Drain, ohne interne Pull-ups.
3,3-V-Seite: Source + 10k nach +3V3, 5-V-Seite: Drain + 10k nach +5V.

ESP_RXD 3 Variante A: D1 mini ESP32 (gesteckt, Standard)
Bestueckt wird ENTWEDER U1 ODER Block 4 - nie beides.
Programmieren ueber die USB-Buchse des D1 mini.
IO25/IO26 bleiben frei fuer die Maus (Version 2).

4 Variante B: ESP32-WROOM-32E aufgeloetet (wenn kein D1 mini da ist)
U2, U3, C1-C5, R5-R7, D1, SW1, SW2, J3 nur in dieser Variante.
Programmieren: USB-Seriell-Adapter an J3, BOOT halten, RESET tippen.

Fertigung JLCPCB 2 Lagen - Regelsatz: Platinen/regeln/regelsatz-jlcpcb.md
Nach github.com/Hamberthm/esp32-bt2ps2 - Version 1: nur Tastatur

Sheet: /
File: bt2ps2.kicad_sch
Title: ESP32 Bluetooth -> PS/2 Tastatur-Adapter

Size: A3 | Rev: 1 | F Date: 2026-09-19
KiCad E.D.A. 10.0.3 | Id: 1/1

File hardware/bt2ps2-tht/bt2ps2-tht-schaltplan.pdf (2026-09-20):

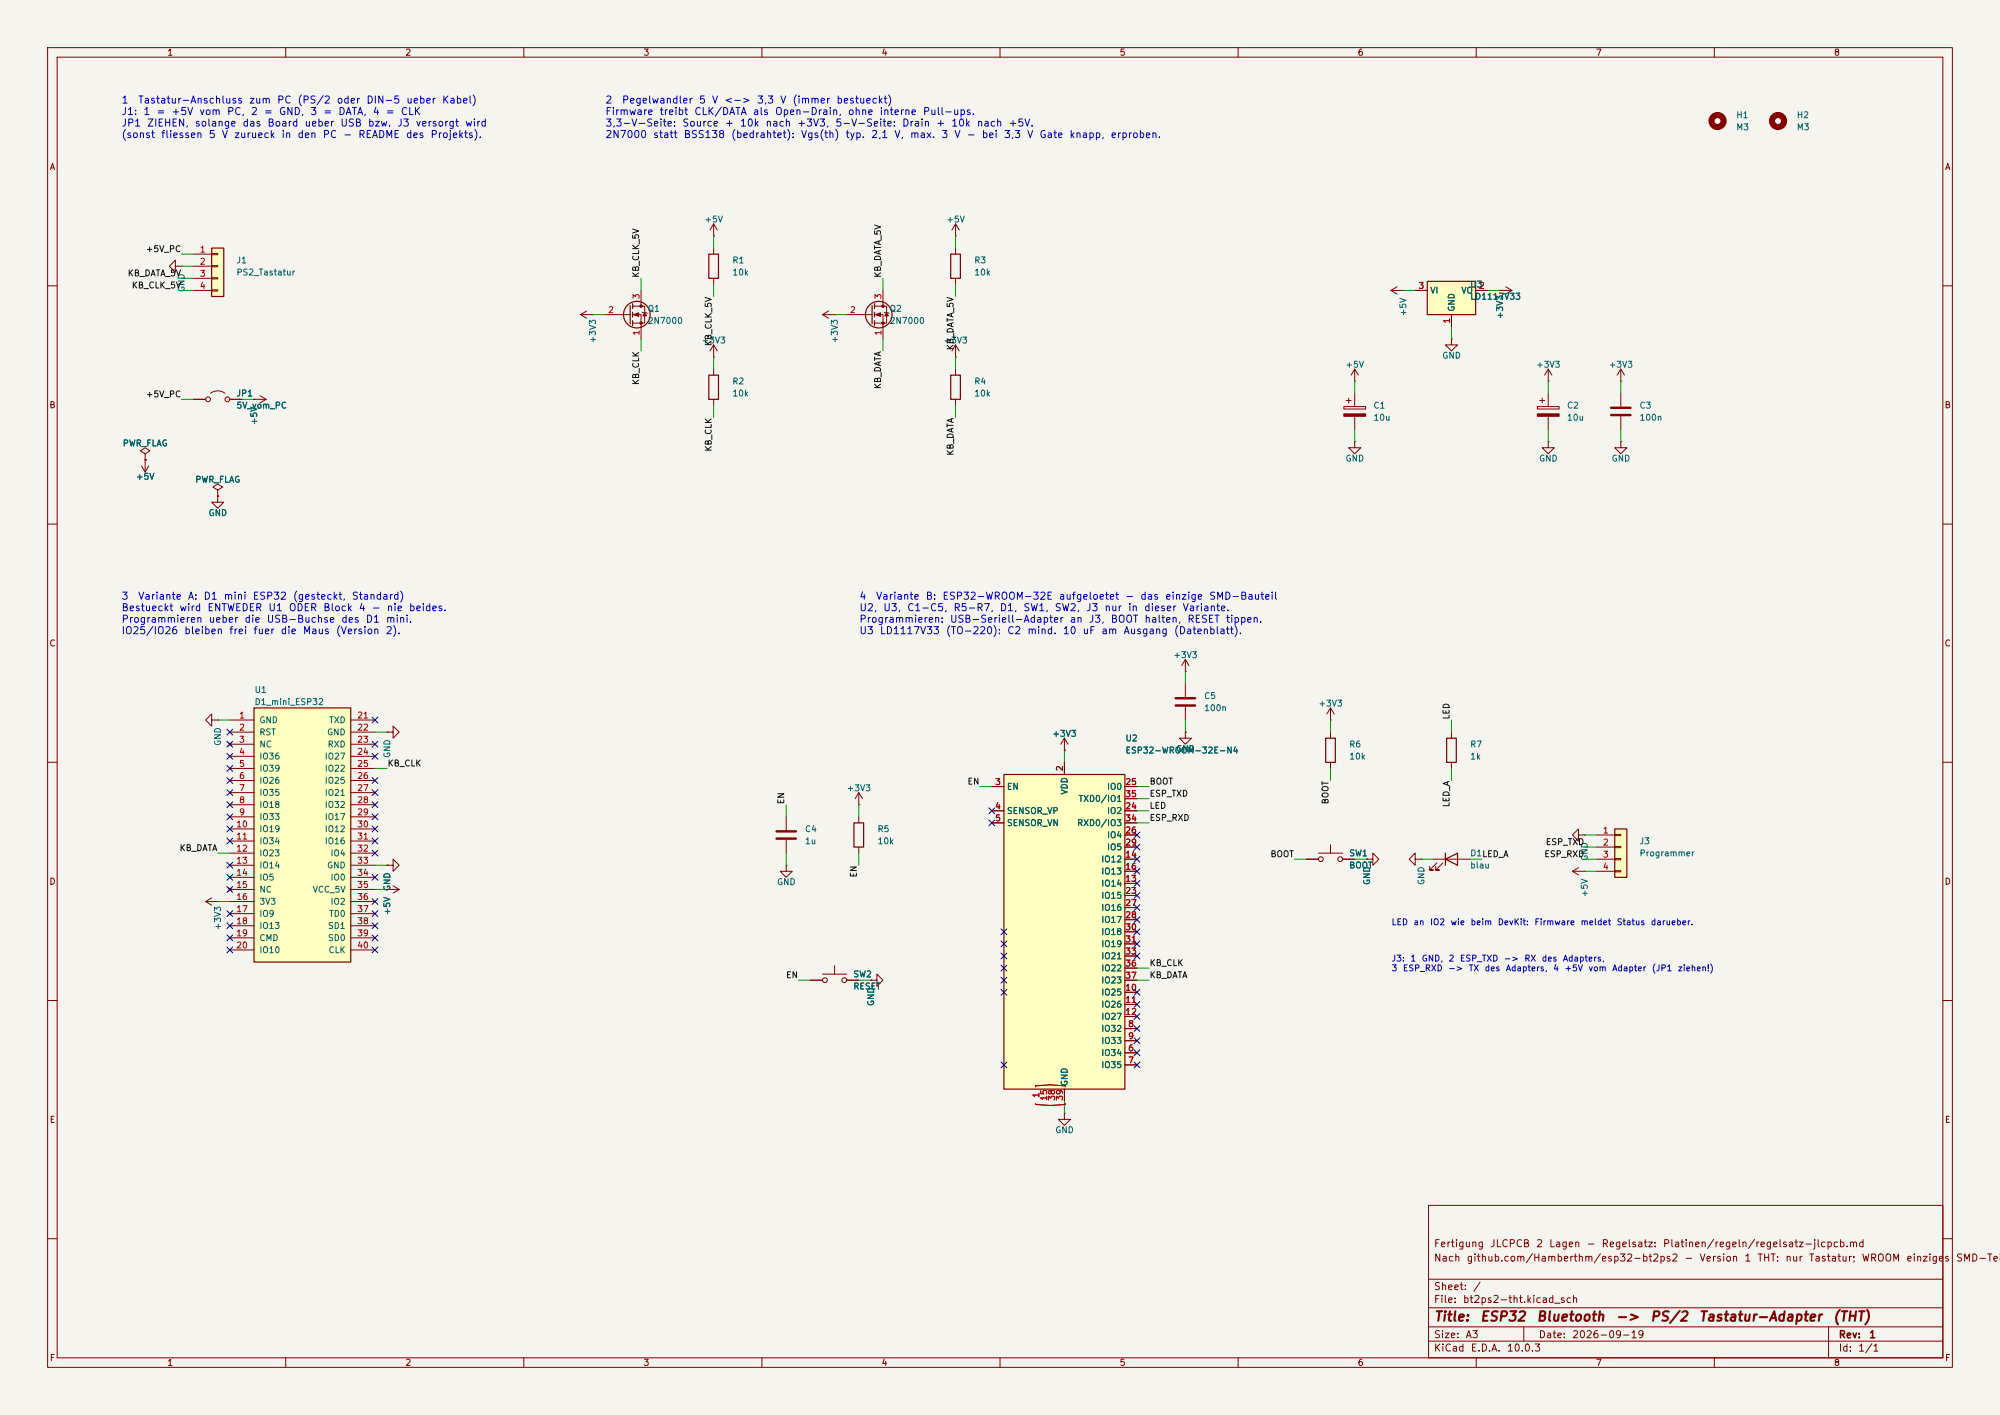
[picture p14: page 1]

1 Tastatur-Anschluss zum PC (PS/2 oder DIN-5 ueber Kabel)
J1: 1 = +5V vom PC, 2 = GND, 3 = DATA, 4 = CLK
JP1 ZIEHEN, solange das Board ueber USB bzw. J3 versorgt wird
(sonst fliessen 5 V zurueck in den PC - README des Projekts).

2 Pegelwandler 5 V <-> 3,3 V (immer bestueckt)
Firmware treibt CLK/DATA als Open-Drain, ohne interne Pull-ups.
3,3-V-Seite: Source + 10k nach +3V3, 5-V-Seite: Drain + 10k nach +5V.
2N7000 statt BSS138 (bedrahtet): Vgs(th) typ. 2,1 V, max. 3 V - bei 3,3 V Gate knapp, erproben.

LED an IO2 wie beim DevKit: Firmware meldet Status darueber. 3 Variante A: D1 mini ESP32 (gesteckt, Standard)
Bestueckt wird ENTWEDER U1 ODER Block 4 - nie beides.
Programmieren ueber die USB-Buchse des D1 mini.
IO25/IO26 bleiben frei fuer die Maus (Version 2).

4 Variante B: ESP32-WROOM-32E aufgeloetet - das einzige SMD-Bauteil
U2, U3, C1-C5, R5-R7, D1, SW1, SW2, J3 nur in dieser Variante.
Programmieren: USB-Seriell-Adapter an J3, BOOT halten, RESET tippen.

Fertigung JLCPCB 2 Lagen - Regelsatz: Platinen/regeln/regelsatz-jlcpcb.md
Nach github.com/Hamberthm/esp32-bt2ps2 - Version 1 THT: nur Tastatur; WROOM einziges SMD-Teil

Sheet: /
File: bt2ps2-tht.kicad_sch
Title: ESP32 Bluetooth -> PS/2 Tastatur-Adapter (THT)

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

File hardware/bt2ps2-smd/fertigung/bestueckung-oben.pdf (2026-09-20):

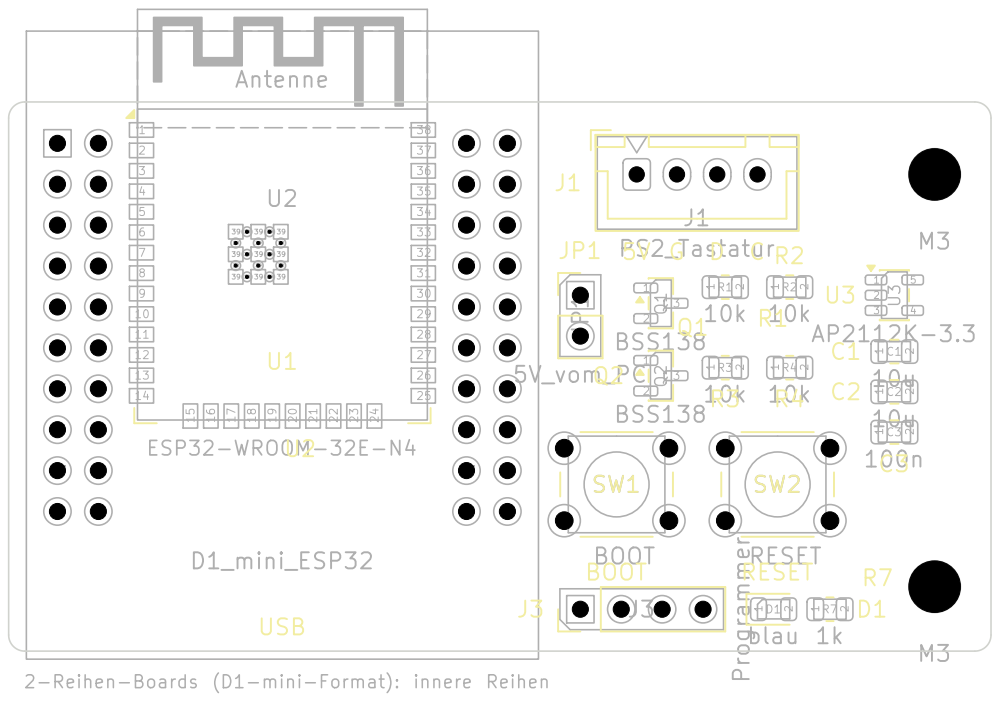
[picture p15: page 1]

Size: A4 | Rev:
KiCad E.D.A. 10.0.3 | Id: 1/1

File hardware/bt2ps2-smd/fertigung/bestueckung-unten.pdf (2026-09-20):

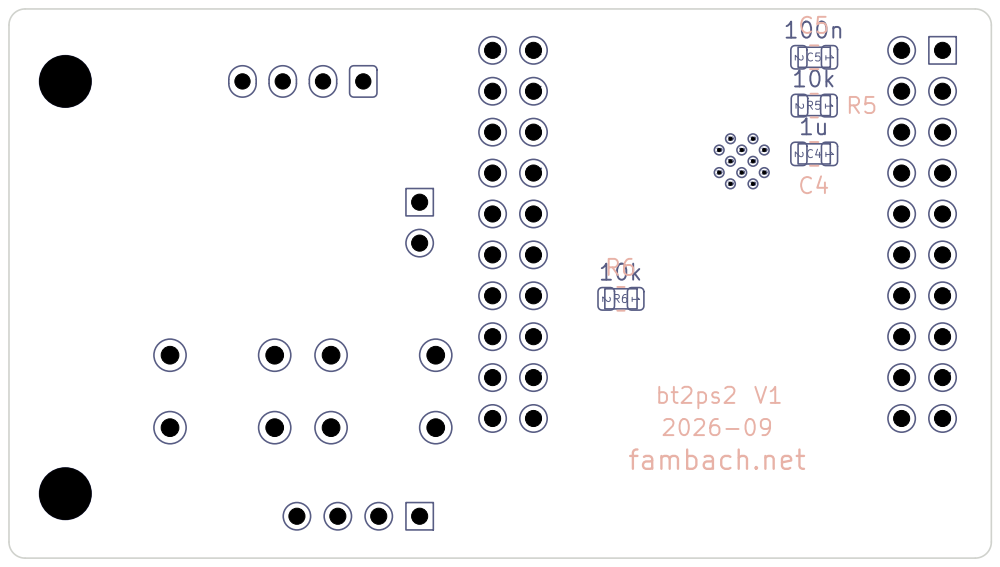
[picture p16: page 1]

Size: A4 | Rev:
KiCad E.D.A. 10.0.3 | Id: 1/1

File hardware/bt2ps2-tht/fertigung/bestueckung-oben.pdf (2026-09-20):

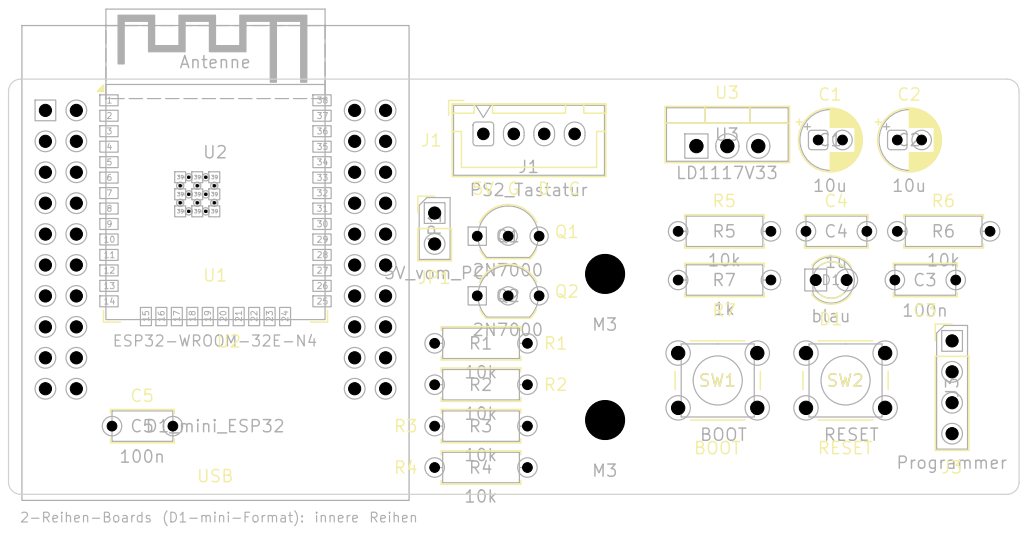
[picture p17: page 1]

Size: A4 | Rev:
KiCad E.D.A. 10.0.3 | Id: 1/1

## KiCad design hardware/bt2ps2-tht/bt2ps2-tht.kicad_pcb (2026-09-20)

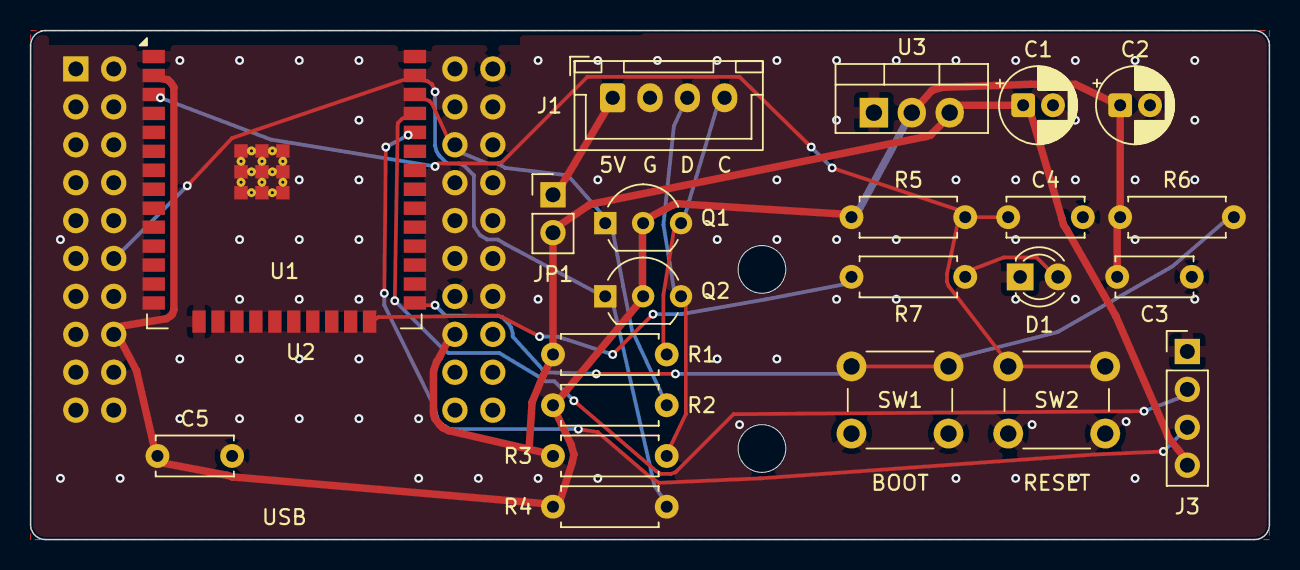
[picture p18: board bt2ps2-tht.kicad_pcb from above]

Board: 2 copper layers, 83.0 x 34.1 mm, 25 parts (0 on the bottom side), 14 nets.

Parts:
C1, C2: 10u; CP_Radial_D5.0mm_P2.00mm
C3, C5: 100n; C_Disc_D5.0mm_W2.5mm_P5.00mm
C4: 1u; C_Disc_D5.0mm_W2.5mm_P5.00mm
D1: blau; LED_D3.0mm
H1, H2: M3; MountingHole_3.2mm_M3
J1: PS2_Tastatur; JST_XH_B4B-XH-A_1x04_P2.50mm_Vertical
J3: Programmer; PinHeader_1x04_P2.54mm_Vertical
JP1: 5V_vom_PC; PinHeader_1x02_P2.54mm_Vertical
Q1, Q2: 2N7000; TO-92_Inline_Wide
R1, R2, R3, R4, R5, R6: 10k; R_Axial_DIN0207_L6.3mm_D2.5mm_P7.62mm_Horizontal
R7: 1k; R_Axial_DIN0207_L6.3mm_D2.5mm_P7.62mm_Horizontal
SW1: BOOT; SW_PUSH_6mm
SW2: RESET; SW_PUSH_6mm
U1: D1_mini_ESP32; D1_mini_ESP32_Sockel
U2: ESP32-WROOM-32E-N4; ESP32-WROOM-32E
U3: LD1117V33; TO-220-3_Vertical

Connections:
+3V3: C2.1, C3.1, C5.1, Q1.2, Q2.2, R2.1, R4.1, R5.1, R6.1, U1.16, U2.2, U3.2
+5V: C1.1, J3.4, JP1.2, R1.1, R3.1, U1.35, U3.3
/+5V_PC: J1.1, JP1.1
/BOOT: R6.2, SW1.1, U2.25
/EN: C4.1, R5.2, SW2.1, U2.3
/ESP_RXD: J3.3, U2.34
/ESP_TXD: J3.2, U2.35
/KB_CLK: Q1.1, R2.2, U1.25, U2.36
/KB_CLK_5V: J1.4, Q1.3, R1.2
/KB_DATA: Q2.1, R4.2, U1.12, U2.37
/KB_DATA_5V: J1.3, Q2.3, R3.2
/LED: R7.1, U2.24
/LED_A: D1.2, R7.2
GND: C1.2, C2.2, C3.2, C4.2, C5.2, D1.1, J1.2, J3.1, SW1.2, SW2.2, U1.1, U1.22, U1.33, U2.1, U2.15, U2.38, U2.39, U3.1

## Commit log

2026-09-19 Add hardware: SMD and THT carrier boards (KiCad 10, untested)
    Two carrier boards for the adapter, keyboard only (v1): a plugged-in D1 mini
    ESP32 or a soldered ESP32-WROOM-32E, BSS138/2N7000 level shifters, JST-XH
    connector for a PS/2 or AT cable. KiCad projects, Gerbers for JLCPCB,
    schematics, assembly drawings and BOMs. Not manufactured or tested yet.
    [bt2ps2-tht.kicad_pcb, bt2ps2-tht.kicad_sch, bt2ps2.kicad_pcb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]
2026-09-20 hardware: 3D-printed enclosures for both boards (OpenSCAD + STL, untested)
    [bt2ps2-gehaeuse.scad, bt2ps2-smd-deckel.stl, bt2ps2-smd-schale.stl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]
2026-09-20 hardware/case: split horizontally, four M3 from below, board on two of them
    [bt2ps2-gehaeuse.scad, bt2ps2-smd-deckel.stl, bt2ps2-smd-oberteil.stl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]
2026-09-20 hardware: pick-and-place files for both boards
    [bt2ps2-jlcpcb-positionen.csv, bt2ps2-tht-jlcpcb-positionen.csv, bt2ps2-tht.kicad_pcb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]
2026-09-20 hardware: component references in the silkscreen on both boards
    [bt2ps2-tht.kicad_pcb, bt2ps2.kicad_pcb]
2026-10-09 hardware: Signalnetze im Schaltplan als Leitungen statt Labels
    Stummel und Labels der Signalnetze durch direkte Leitungen ersetzt
    (ein Label pro Netz bleibt fuer den Netznamen). Power-Symbole unveraendert.
    Netzliste vorher/nachher identisch (kicad-cli 10.0.6), Bauteile noch
    nicht neu angeordnet.
    Claude-Session: https://claude.ai/code/session_011oCCcpbxxbJKmkNL9JorAb
    [bt2ps2-tht.kicad_sch, bt2ps2.kicad_sch]
2026-10-19 hardware: note planned reverse-protection diode in the PC 5 V path
    Claude-Session: https://claude.ai/code/session_01MjmmQSV54ep4Q9qDM3ZD4r
2026-10-19 Build with ESP-IDF 6.1 (enable BLE 4.2 legacy API)
    The committed sdkconfig (generated by ESP-IDF 5.3.0) had
    CONFIG_BT_BLE_42_FEATURES_SUPPORTED unset, so linking under 6.x failed
    with undefined references to esp_ble_gap_set_scan_params,
    esp_ble_gap_start_scanning and esp_ble_resolve_adv_data.
    - sdkconfig.defaults: set BT_BLE_42_FEATURES_SUPPORTED and BT_BLE_42_SCAN_EN
    - sdkconfig: regenerated with ESP-IDF 6.1.0 for target esp32
    - README: build-tested with ESP-IDF 6.1.0 and 5.3.0
2026-10-19 Fix PS/2 sender on slow hosts (AltGr, swallowed keys, stuck modifiers)
    On a Micro 8088 with DOS 3.31/KEYB GR, AltGr worked only sometimes and
    Ctrl/Alt could get stuck, while a real PS/2 keyboard worked fine.
    - Retry a byte while the host inhibits the clock (up to 100 ms) instead
    of silently dropping the rest of the packet after 1.5 ms
    - Detect a host abort (CLK held low) before each falling edge and
    retransmit the byte, like a real keyboard
    - When the host requests to send, let the command be handled and then
    continue the interrupted packet
    - Answer Resend (FE) by repeating the last byte instead of sending FA
    - 1 ms gap between bytes of a packet (as in HIDman)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
2026-10-31 Faster BLE reconnect: stop scan on bonded device, enable GATT cache
    The BLE daemon waited for the full 5 s scan before connecting to the
    bonded keyboard. It now stops scanning as soon as a bonded address
    advertises (scan stop releases esp_hid_scan via SCAN_STOP_COMPLETE).
    CONFIG_BT_GATTC_CACHE_NVS_FLASH skips GATT discovery on reconnect.
    Builds with ESP-IDF 5.3; not yet tested on hardware.
    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
2026-10-31 SMD board V2 (WIP): drop D1 mini socket, rotate WROOM, shrink to 49x30 mm
    All parts on the front; R5/R6/C4/C5 next to the module pins. Parts placed,
    DRC clean apart from the still unrouted connections. Schematic notes updated.
    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
2026-10-31 SMD board V2: route with Freerouting, regenerate outputs, adapt enclosure
    - Board 49 x 31 mm, module moved down 1 mm for routing room
    - Freerouting (45 deg), keepout for top-layer traces under the WROOM,
    GND through the pours; DRC clean, schematic parity clean
    - New Gerbers, positions, BOM, assembly drawing, project zip, 3D renders
    - Removed bottom assembly drawing (no bottom parts) and the stale iBOM
    - Enclosure: SMD variant without USB cutout, antenna strip on the left
    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
2026-10-31 THT schematic PDF/SVG: re-export after the wiring change
    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
2026-10-31 Silkscreen: label J3 pins G TX RX 5V on both boards
    Regenerate gerbers, renders, assembly PDFs and project zips.
    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
2026-10-31 SMD V2: 6-pin J3 with DTR/RTS auto-reset
    J3 now carries GND TX RX 5V DTR RTS; Q3/Q4 (MMBT3904) and R8/R9 form the
    usual ESP32-DevKitC auto-reset. Pins 1-4 unchanged. Re-routed with
    Freerouting, DRC clean with schematic parity. Enclosure J3 cutout and LED
    hole adapted; outputs regenerated.
    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
2026-10-31 Startup pairing scan: connect a bonded keyboard as soon as it advertises
    The scan at power-on waited for the full BLE scan plus the BT Classic
    inquiry before connecting the bonded keyboard (seen ~10 s late in a
    monitor log). Stop the BLE scan early for a bonded device and skip the
    BT Classic inquiry in that case, as the reconnect daemon already does.
    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
2026-10-31 Silkscreen: mark LED anode with + on both boards
    SMD: R7 moved 0.6 mm right to make room, its two tracks follow.
    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
2026-11-01 Split THT board into D1 mini and WROOM boards
    - THT D1 mini: socket, level shifter, J1/JP1 only, 60 x 34.2 mm
    - THT WROOM: LD1117V33 lying flat (TO-220 horizontal), 6-pin J3 with
    DTR/RTS auto-reset (BC547), 63 x 44 mm
    - Both routed with Freerouting, ERC/DRC clean, M3 holes on the long axis
    - Case: variants tht-d1 and tht-wroom, STLs and previews
    - Old combined THT board kept in bt2ps2-tht for reference
    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
2026-11-01 Split hardware into v1 (built, tested) and v2 (current)
    - v1/tht, v1/smd: boards as built, with photos
    - v2/smd, v2/tht-d1, v2/tht-wroom: current revision
    - READMEs per version; root README links updated
    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
